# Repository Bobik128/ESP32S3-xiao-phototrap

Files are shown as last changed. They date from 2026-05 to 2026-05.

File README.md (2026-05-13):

# ESP32S3 XIAO Phototrap

ESP32S3 XIAO-based low-power phototrap project.

<p align="center">
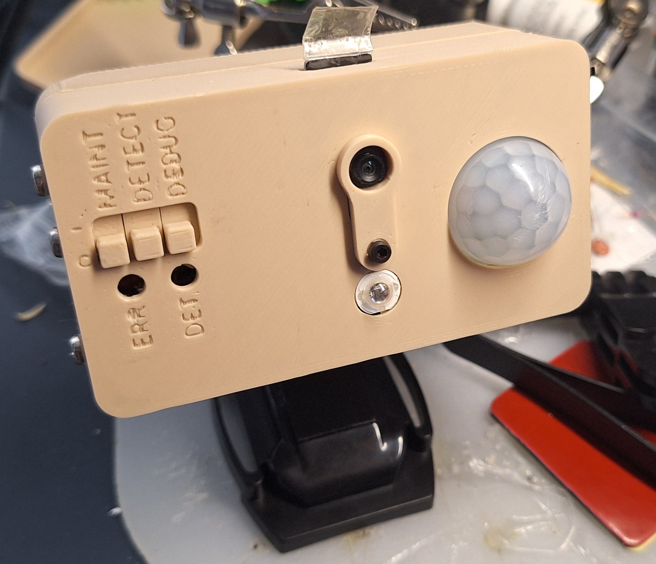
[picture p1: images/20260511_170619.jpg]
  
</p>

This guide shows how to build the phototrap step by step.

First, print all required parts. The files are located in the `cad` directory or on [Onshape](https://cad.onshape.com/documents/ead58119c3828b68d815a62f/w/7087faa25839fe28733057f0/e/a371d4849fa89fe6a0035750).

> https://cad.onshape.com/documents/ead58119c3828b68d815a62f/w/7087faa25839fe28733057f0/e/a371d4849fa89fe6a0035750
> 
> if it doesnt work, just copy the url and put it in browser manually

For printing, I used PLA because it is easy to print with, but for outdoor usage I would recommend ASA.

---

# Features

The phototrap has 3 switches:

- **Maintenance**
- **Detect**
- **Debug**

## Maintenance Mode

The **Maintenance** switch enables maintenance mode.

In this mode, the ESP32 starts a Wi-Fi access point that you can connect to.  
Then open `192.168.4.1` in your browser to access the web interface.

There you can:

- Change SSID and password
- Modify camera settings
- View a live stream
- Turn the IR LED on/off
- Monitor battery level
- View error messages
- And more

The interface supports both:

- Czech
- English

---

## Detect Switch

The **Detect** switch enables automatic recording.

When the PIR sensor detects movement, the ESP32 automatically starts recording video.

---

## Debug Switch

The **Debug** switch enables a small indicator LED below the switch.

The LED lights up whenever movement is detected.

---

## Error LED

The **Error LED** lights up whenever a critical error occurs.

Typical causes:

- Missing SD card
- Broken SD card
- Camera initialization failure

When this happens, the ESP32 also creates a Wi-Fi network and shows the exact error message on the web interface.

---

# Operation

When movement is detected while the **Detect** switch is enabled, recording starts automatically.

Recording continues as long as movement is still being detected.

---

## Power Consumption

When idle, the phototrap consumes approximately **0.3mA**.

With a **10Wh battery**, it can theoretically last for over a year.

The ESP32 wakes up only when:

- Movement is detected
- The maintenance pin is activated

---

## Downloading Videos

Recorded videos can be downloaded:

- Directly from the SD card
- Through the web interface

> **Note:**  
> Videos are encoded in a format that is not natively supported on many mobile phones.  
> Use the VLC player app for playback.

---

## PIR Sensitivity

The PIR sensor has 2 potentiometers accessible from the side of the phototrap:

- **Sensitivity adjustment**
- **Detection hold time**

---

# Miscellaneous

There are 4 possible back cover variants:

- Battery / no battery
- GoPro mount / no GoPro mount

---

# Build Process

# Required Parts

## Screws and Nuts

- 4x M3 × 6mm
- 3x M2 × 4mm
- 2x self-tapping screws, 2mm × 6mm (for mounting the PIR sensor)
- 1x M2 nut

---

## Electronics

- ESP32S3 XIAO Sense with camera expansion board
- OV3660 camera with ~21mm cable
  - OV2640 is not recommended because it cannot reliably enter standby mode and consumes around 20mA instead of ~0.3mA
  - OV5640 has not been tested
- 2.4GHz antenna
- IR LED on a 20mm star cooling pad (850nm recommended)
- Li-Pol battery — specifically `954060 3000mAh 1S / 3.7V`
- Battery connector for the PCB (I used JST-XH 2.54mm)
- 3x DPS switches — `SS12D00G4`
- 3mm red LED
- 3mm blue or green LED
- PIR sensor `HC-SR501`
- NPN transistor (2N2222 recommended)

---

## Resistors

- 2x 330Ω
- 1x 470Ω
- 1x 680Ω
- 2x 1kΩ

For the IR LED, use higher-power resistors (around 1W) and create a resistance between **8Ω and 10Ω**.

Example combination:

- 2.2Ω + 6.8Ω

---

## Additional Materials

- Small prototyping PCB (DPS board)

The exact size does not matter because it must be trimmed to fit.

---

# PIR Sensor Modification

The HC-SR501 normally operates from **4.5–20V**, which is not ideal for this project.

To make it work directly from **3.3V**:

1. Remove the voltage regulator
2. Remove the diode
3. Replace them with solder bridges or short wires

Like this:

<p align="center">
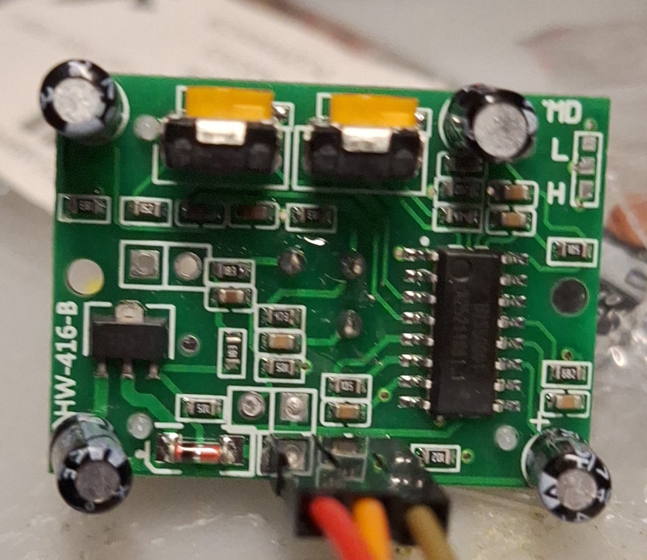
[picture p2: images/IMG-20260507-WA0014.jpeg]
  
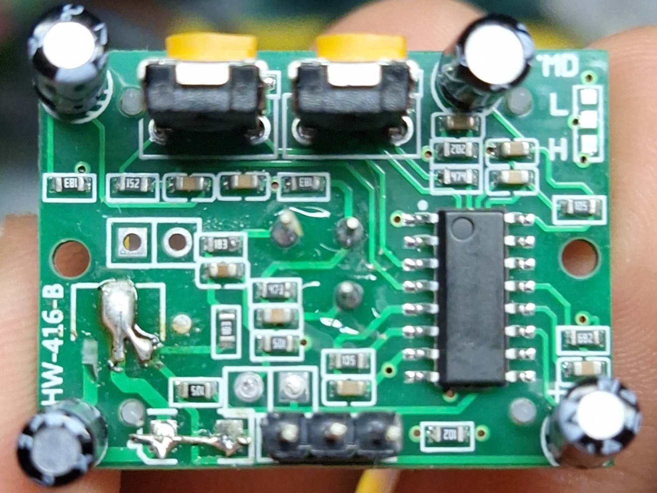
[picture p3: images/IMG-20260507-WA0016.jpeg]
  
</p>

After this modification, the PIR sensor can run directly from 3.3V.

---

# IR LED

<p align="center">
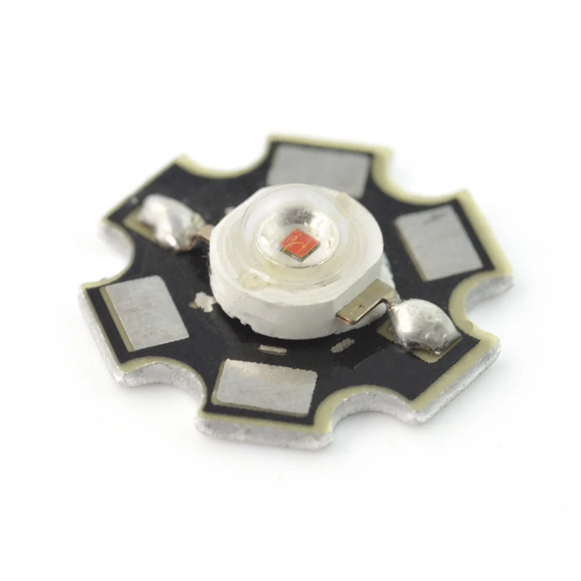
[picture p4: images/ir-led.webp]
  
</p>

Solder wires to the IR LED:

- `+`
- `-`

Before snapping the LED into place, insert the **M2 nut** into its slot.

Then snap the IR LED into position.

---

# ESP32 Assembly

First, separate the ESP32S3 XIAO Sense into its parts:

- Main board
- Expansion board
- Camera
- Antenna

## Assembly Steps

1. Connect the antenna to the main board
2. Slide the camera into its slot
3. Connect the camera to the expansion board
4. Insert the main board into the top slot
5. While inserting it, connect it to the expansion board
6. Route the antenna cable through the cable slot
7. Secure everything using screws or glue

---

# Main PCB

This is the most difficult part because the board must be assembled manually.

The exact component placement is not critical except for:

- Switches
- LEDs
- Battery connector

For placement details, check the Onshape CAD model linked above.

Recommended PCB size:

- Approximately `3.2 × 3.3 cm`

Trim it as necessary.

---

## Circuit Diagram

<a href="images/Phototrap circuit.pdf">
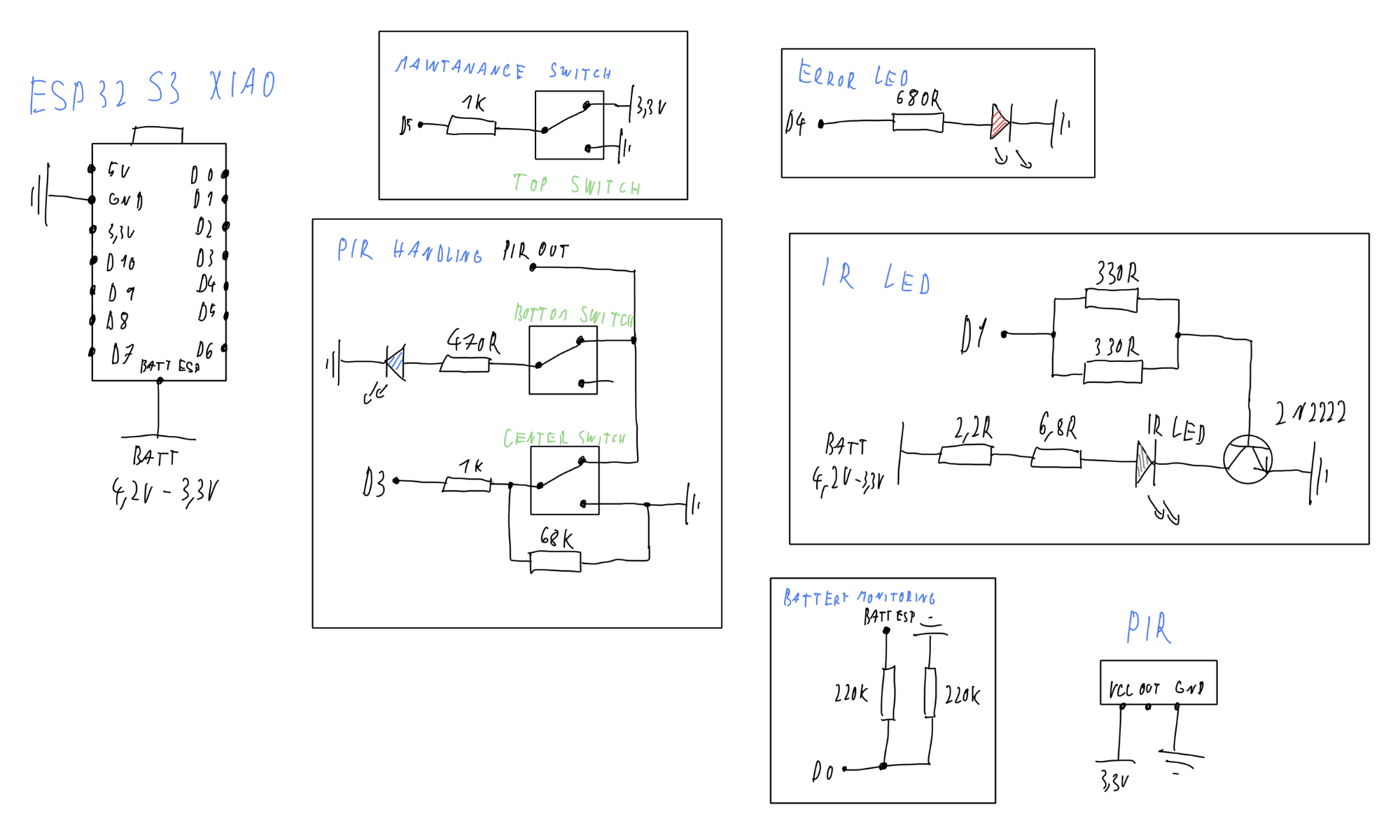
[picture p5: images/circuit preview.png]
  
</a>

---

## PCB Assembly Example

<p align="center">
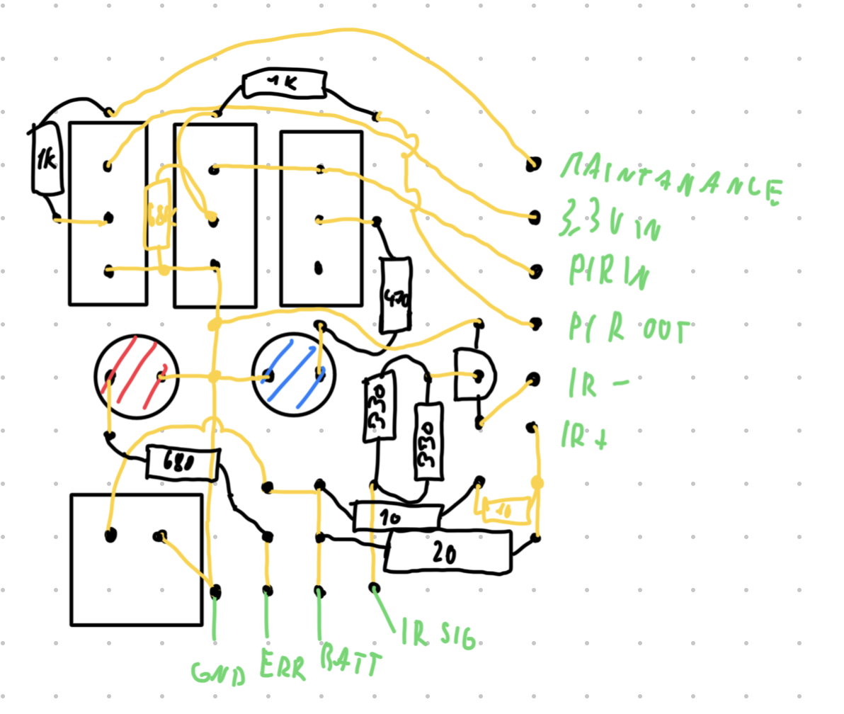
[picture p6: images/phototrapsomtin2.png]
  
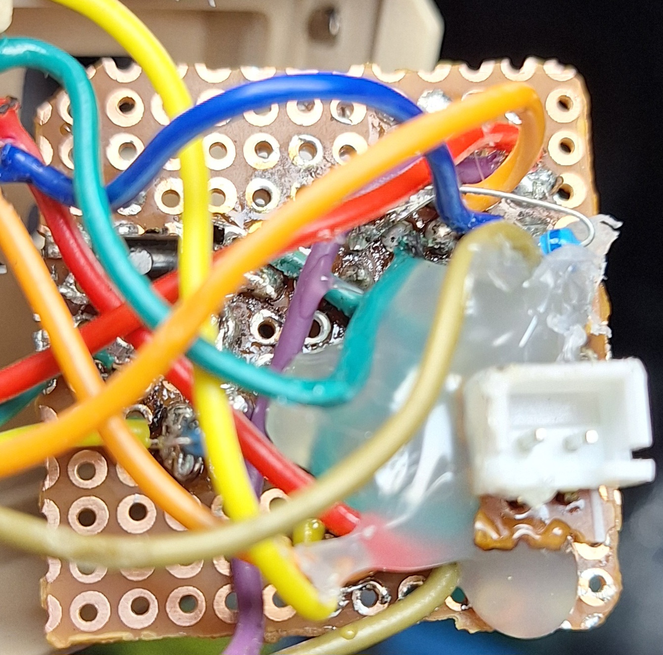
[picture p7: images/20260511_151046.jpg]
  
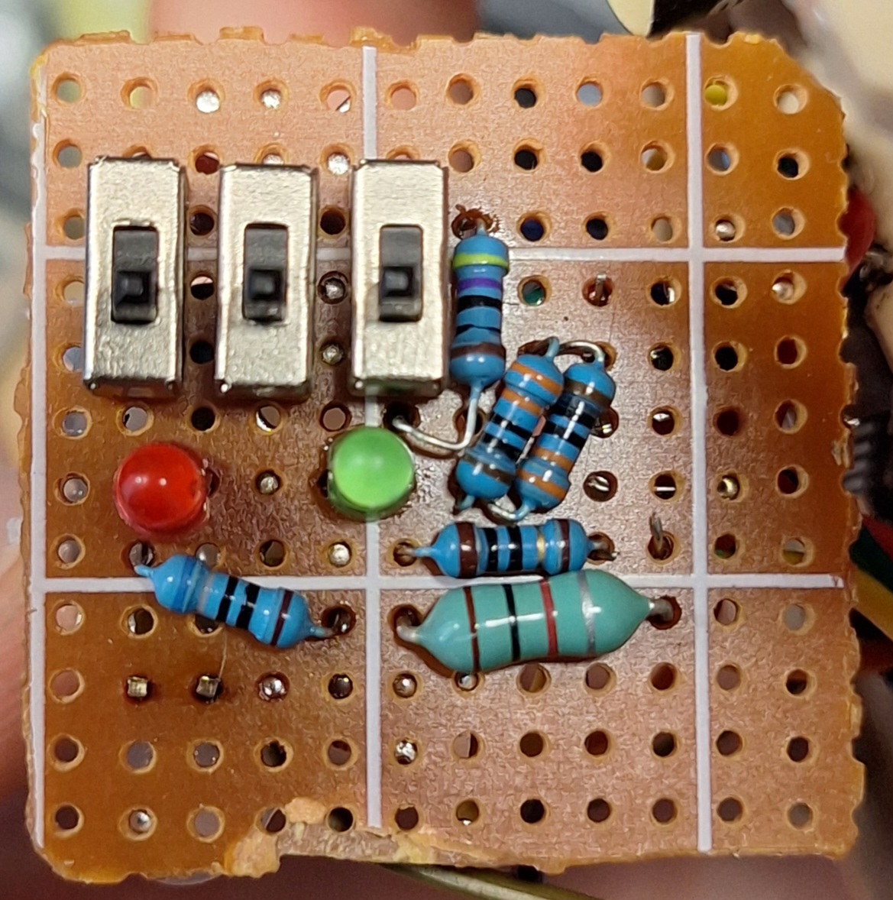
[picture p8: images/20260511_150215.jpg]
  
</p>

---

# Final Assembly

Once everything is assembled:

1. Connect all wires according to the circuit diagram
2. Upload the firmware
3. Test the device

---

# Uploading the Firmware

1. Open the `.ino` file in Arduino IDE
2. Place the `.ino` file into a folder with the same name as the file
3. Install the ESP32 board package
4. Enable **PSRAM**
5. Select the correct board
6. Select the correct flash size (8MB)

---

## Pin Configuration

Check that the GPIO assignments match your hardware.

> These are GPIO numbers, not `D#` labels.

```cpp
static const int PIR_PIN    = 4;
static const int MAINT_PIN  = 3;
static const int IR_LED_PIN = 2;
static const int ERROR_PIN  = 5;

// Battery measurement on GPIO1 through 1/2 voltage divider
static const int BAT_ADC_PIN = 1;
````

```
```

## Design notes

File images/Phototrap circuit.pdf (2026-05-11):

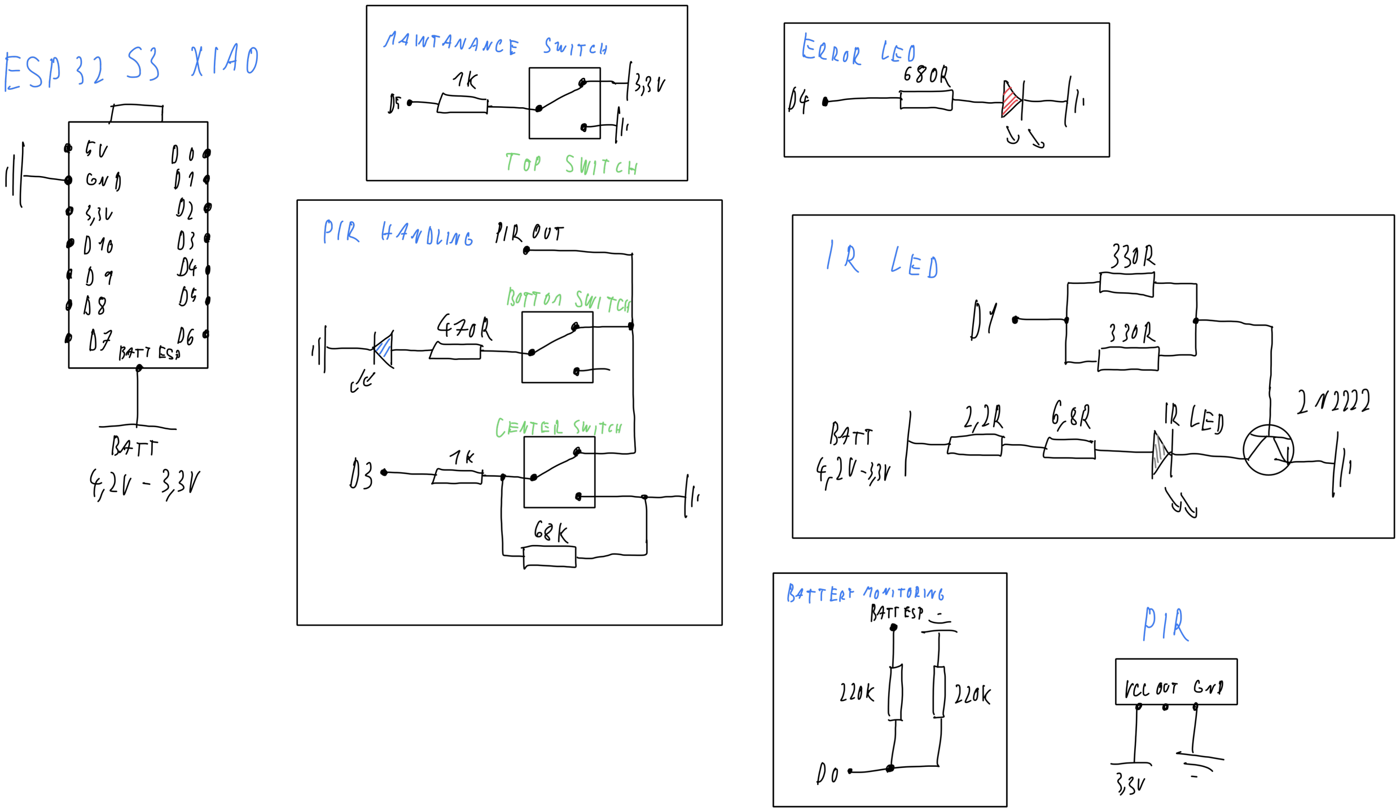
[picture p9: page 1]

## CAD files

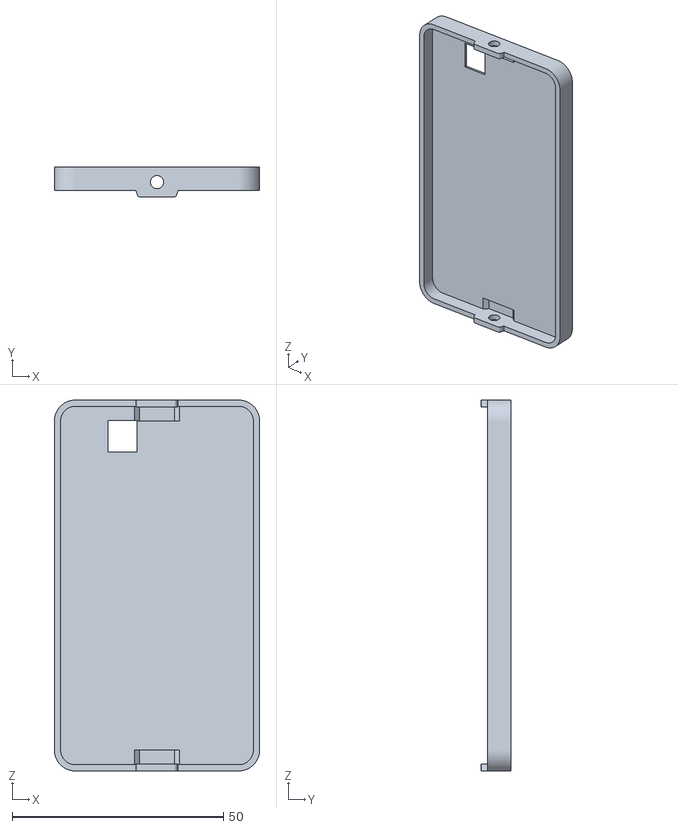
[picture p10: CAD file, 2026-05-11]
cad/stl/main - back-case-no_battery-no_mount.stl
48.6 x 7.03 x 87.8

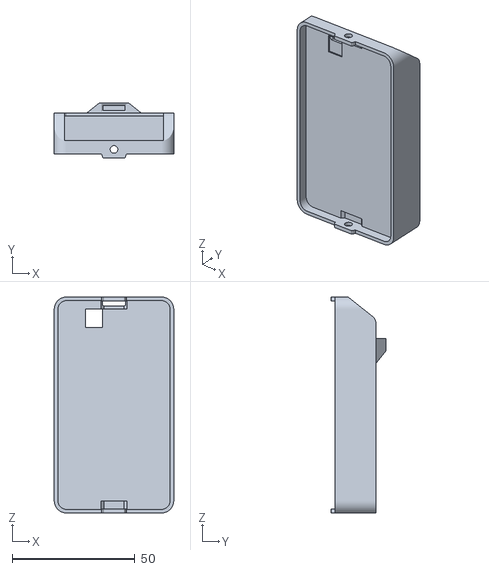
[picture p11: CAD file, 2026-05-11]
cad/stl/main - back-case-no_mount.stl
48.6 x 22.3 x 87.8

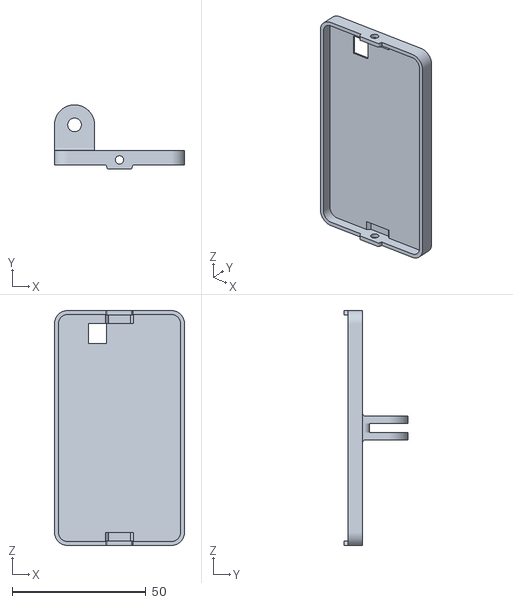
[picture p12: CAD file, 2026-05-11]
cad/stl/main - back-case-no_battery.stl
48.6 x 24.0 x 87.8

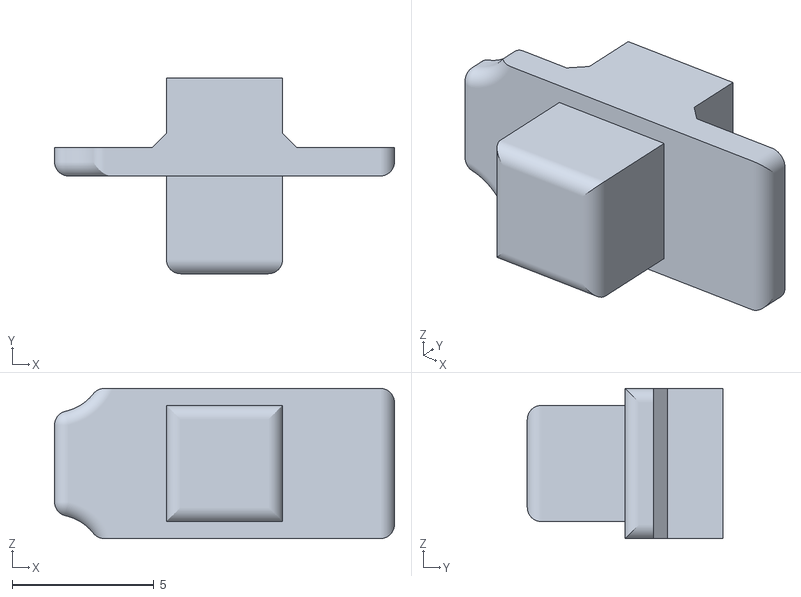
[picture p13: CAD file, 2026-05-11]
cad/stl/Assembly 1 - middle-button.stl
12.0 x 6.90 x 5.30

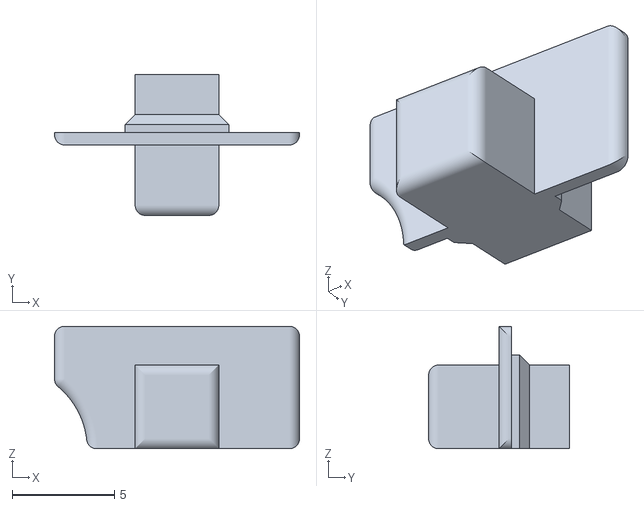
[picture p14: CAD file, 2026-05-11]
cad/stl/Assembly 1 - top-button.stl
12.0 x 6.90 x 6.00

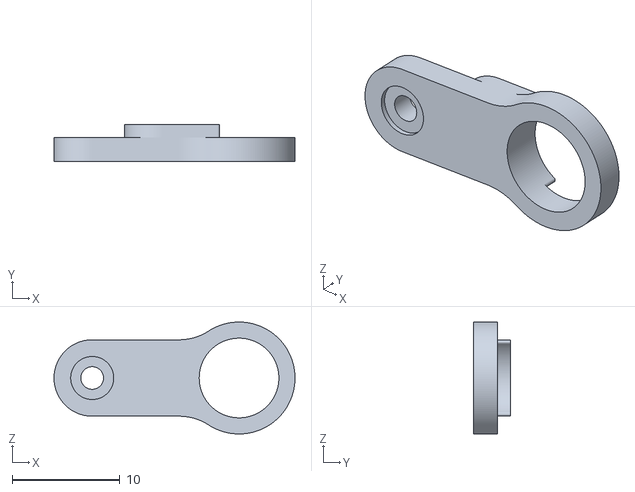
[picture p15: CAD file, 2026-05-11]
cad/stl/Assembly 1 - camera-guard.stl
22.4 x 3.40 x 10.4

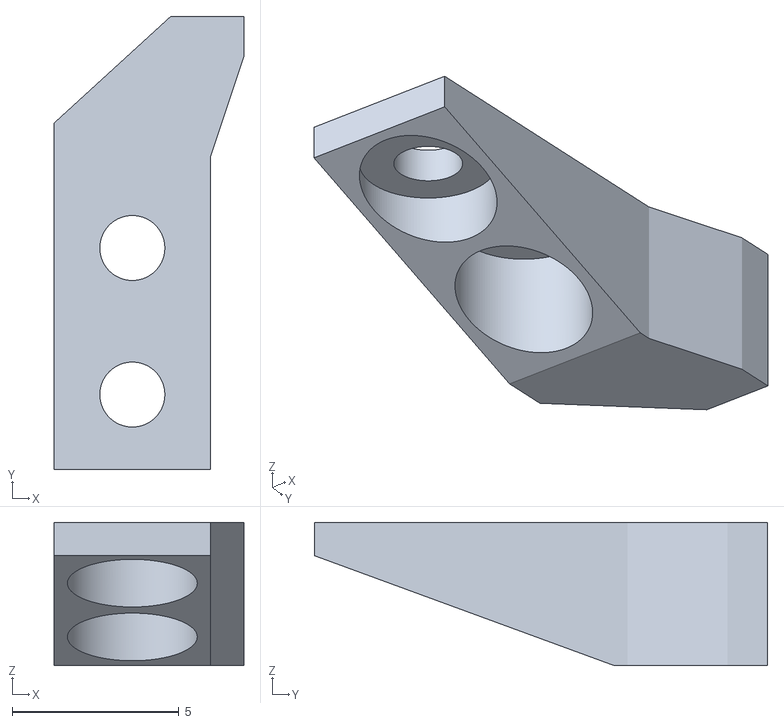
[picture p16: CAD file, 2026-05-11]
cad/stl/Assembly 1 - esp-bracket.stl
5.70 x 13.6 x 4.30

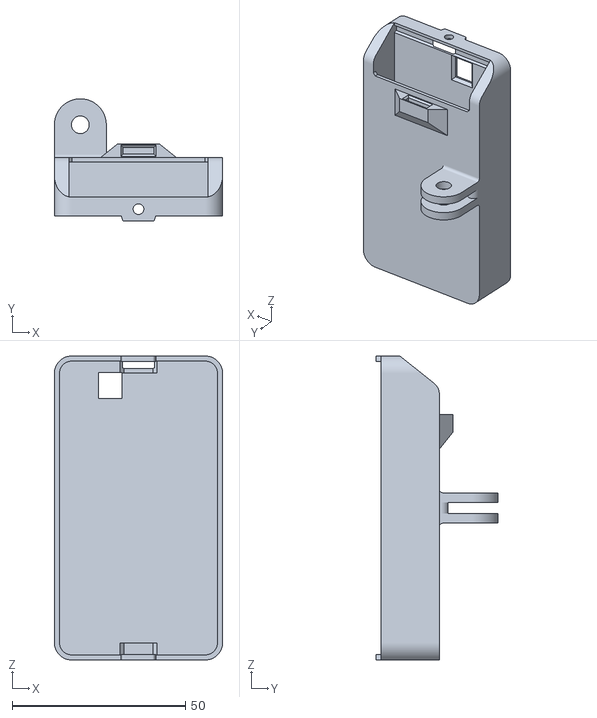
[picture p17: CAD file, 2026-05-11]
cad/stl/Assembly 1 - back-case.stl
48.6 x 35.3 x 87.8

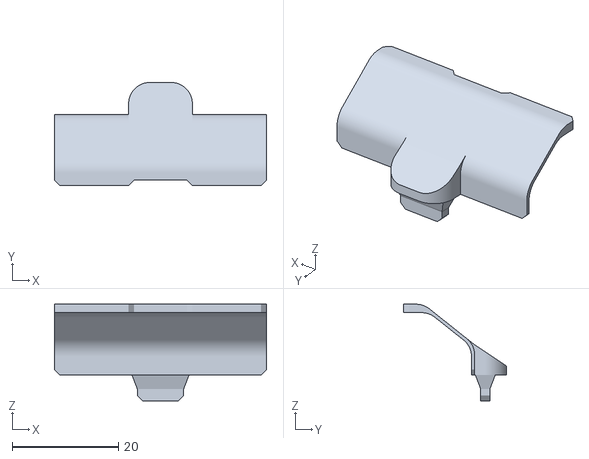
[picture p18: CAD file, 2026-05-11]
cad/stl/Assembly 1 - battery-cover.stl
39.9 x 19.4 x 18.2

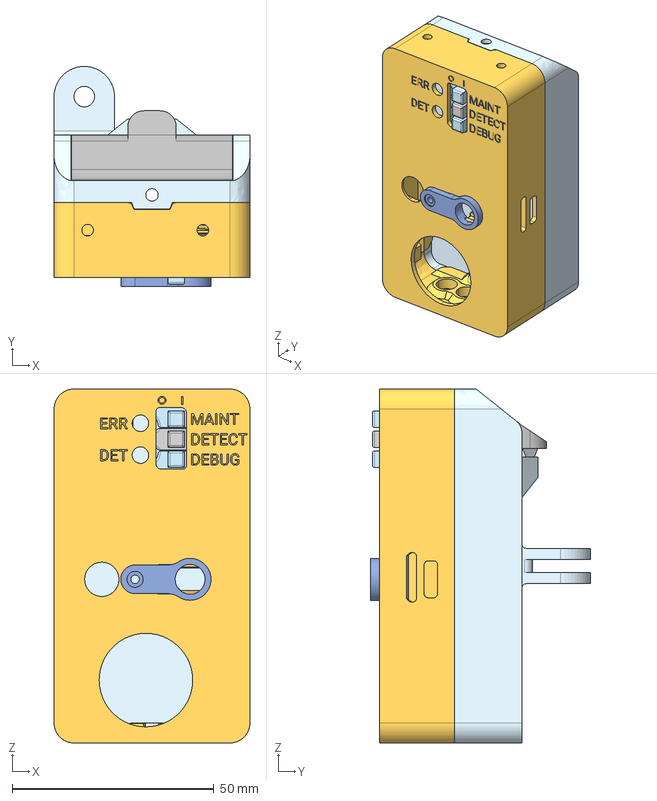
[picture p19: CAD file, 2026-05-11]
cad/phototrap.step
48.6 x 54.6 x 87.8 mm
middle-button
battery-cover
camera-guard
low-button
back-case
top-button
esp-bracket

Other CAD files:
cad/stl/Assembly 1 - low-button.stl

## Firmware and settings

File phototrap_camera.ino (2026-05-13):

#include <Arduino.h>
#include <esp_camera.h>
#include <driver/rtc_io.h>
#include <FS.h>
#include <SD.h>
#include <SPI.h>
#include <WiFi.h>
#include <WebServer.h>
#include <Preferences.h>

// ======================================================================
// Camera pins: XIAO ESP32S3 Sense
// ======================================================================

static const int XCLK_PIN  = 10;
static const int PCLK_PIN  = 13;
static const int VSYNC_PIN = 38;
static const int HREF_PIN  = 47;

static const int D0_PIN = 15;
static const int D1_PIN = 17;
static const int D2_PIN = 18;
static const int D3_PIN = 16;
static const int D4_PIN = 14;
static const int D5_PIN = 12;
static const int D6_PIN = 11;
static const int D7_PIN = 48;

static const int SDA_PIN   = 40;
static const int SCL_PIN   = 39;
static const int PWDN_PIN  = -1;
static const int RESET_PIN = -1;

// ======================================================================
// SD card pins: XIAO ESP32S3 Sense
// NOTE: SD_CS = GPIO21. On the XIAO ESP32S3 Sense, GPIO21 is also tied
// to the onboard user LED, so SD writes visibly flash the onboard LED.
// This is a board-level hardware conflict, not controllable in firmware.
// ======================================================================

static const int SD_CS   = 21;
static const int SD_SCK  = 7;
static const int SD_MISO = 8;
static const int SD_MOSI = 9;

// ======================================================================
// User pins
// ======================================================================

static const int PIR_PIN    = 4;
static const int MAINT_PIN  = 3;
static const int IR_LED_PIN = 2;
static const int ERROR_PIN  = 5;  // HIGH = fatal error / error AP active

// Battery measurement on GPIO1 through 1/2 voltage divider
static const int BAT_ADC_PIN = 1;
static const float BAT_DIVIDER_RATIO = 2.0;

// ======================================================================
// Config files / defaults
// ======================================================================

static const char *DEFAULT_AP_SSID = "Phototrap-AP";
static const char *DEFAULT_AP_PASS = "12345678";
static const char *AP_CONFIG_FILE = "/ap_config.txt";
static const char *CAMERA_CONFIG_FILE = "/camera_config.txt";

String apSsid = DEFAULT_AP_SSID;
String apPass = DEFAULT_AP_PASS;
String uiLang = "en";

Preferences prefs;

// ======================================================================
// Runtime camera settings, loaded from /camera_config.txt
// ======================================================================

static framesize_t cameraFrameSize = FRAMESIZE_FHD;
static String cameraFrameSizeId = "FHD";

static int jpegQuality = 4;     // 4 = best/largest, 63 = worst/smallest
static uint16_t aviFps = 5;
static int xclkHz = 16000000;

static bool cameraVFlip = true;
static bool cameraHMirror = false;
static bool recordingIrLedEnabled = true;

static const uint32_t RECORD_BLOCK_MS = 5000;
static const uint16_t MAX_FRAMES = 2000;

struct CameraResolutionOption {
  const char *id;
  const char *label;
  framesize_t frameSize;
  uint16_t width;
  uint16_t height;
  uint16_t maxFps;
};

static const CameraResolutionOption CAMERA_RES_OPTIONS[] = {
  {"96X96",   "96 x 96",      FRAMESIZE_96X96,   96,   96,   30},
  {"QQVGA",   "160 x 120",    FRAMESIZE_QQVGA,   160,  120,  30},
  {"QCIF",    "176 x 144",    FRAMESIZE_QCIF,    176,  144,  30},
  {"HQVGA",   "240 x 176",    FRAMESIZE_HQVGA,   240,  176,  30},
  {"240X240", "240 x 240",    FRAMESIZE_240X240, 240,  240,  25},
  {"QVGA",    "320 x 240",    FRAMESIZE_QVGA,    320,  240,  25},
  {"CIF",     "400 x 296",    FRAMESIZE_CIF,     400,  296,  20},
  {"HVGA",    "480 x 320",    FRAMESIZE_HVGA,    480,  320,  20},
  {"VGA",     "640 x 480",    FRAMESIZE_VGA,     640,  480,  15},
  {"SVGA",    "800 x 600",    FRAMESIZE_SVGA,    800,  600,  10},
  {"XGA",     "1024 x 768",   FRAMESIZE_XGA,     1024, 768,  8},
  {"HD",      "1280 x 720",   FRAMESIZE_HD,      1280, 720,  6},
  {"SXGA",    "1280 x 1024",  FRAMESIZE_SXGA,    1280, 1024, 5},
  {"UXGA",    "1600 x 1200",  FRAMESIZE_UXGA,    1600, 1200, 5},
  {"FHD",     "1920 x 1080",  FRAMESIZE_FHD,     1920, 1080, 5},
  {"P_HD",    "720 x 1280",   FRAMESIZE_P_HD,    720,  1280, 4},
  {"P_3MP",   "864 x 1536",   FRAMESIZE_P_3MP,   864,  1536, 3},
  {"QXGA",    "2048 x 1536",  FRAMESIZE_QXGA,    2048, 1536, 3}
};

static const size_t CAMERA_RES_OPTION_COUNT =
  sizeof(CAMERA_RES_OPTIONS) / sizeof(CAMERA_RES_OPTIONS[0]);

// ======================================================================
// Globals
// ======================================================================

WebServer server(80);

bool maintenanceActive = false;
bool sdAvailable = false;
bool cameraAvailable = false;

bool recordingActive = false;
bool irLedOverrideActive = false;
bool irLedOutputActive = false;

// Blocking stream/download handlers set this flag if MAINT goes LOW.
// The main loop performs the actual AP shutdown once the handler exits.
bool maintenanceShutdownRequested = false;

String criticalError = "";

uint32_t nextVideoId = 1;

// ======================================================================
// Language helpers
// ======================================================================

bool isCzech() {
  return uiLang == "cs";
}

String tr(const String &en, const String &cs) {
  return isCzech() ? cs : en;
}

String activeLangClass(const String &lang) {
  return uiLang == lang ? " activeLang" : "";
}

void saveUiLanguage(const String &lang) {
  if (lang != "en" && lang != "cs") return;

  uiLang = lang;

  prefs.begin("phototrap", false);
  prefs.putString("ui_lang", uiLang);
  prefs.end();
}

void handleSetLanguage() {
  String lang = server.arg("lang");

  if (lang == "cs" || lang == "en") {
    saveUiLanguage(lang);
  }

  server.sendHeader("Location", "/");
  server.send(303);
}

// ======================================================================
// Formatting / log helpers
// ======================================================================

String formatFileSize(uint64_t bytes) {
  if (bytes >= 1024ULL * 1024ULL) {
    return String((float)bytes / (1024.0f * 1024.0f), 2) + " MB";
  }

  if (bytes >= 1024ULL) {
    return String((float)bytes / 1024.0f, 1) + " KB";
  }

  return String((uint32_t)bytes) + " B";
}

static const size_t LOG_LINES = 120;
String logBuffer[LOG_LINES];
size_t logIndex = 0;

void logLine(const String &msg) {
  String line = "[" + String(millis()) + "] " + msg;

  Serial.println(line);

  logBuffer[logIndex % LOG_LINES] = line;
  logIndex++;

  if (sdAvailable) {
    File f = SD.open("/phototrap.log", FILE_APPEND);
    if (f) {
      f.println(line);
      f.close();
    }
  }
}

String logText() {
  String text;

  size_t count = min((size_t)LOG_LINES, logIndex);
  size_t start = (logIndex > LOG_LINES) ? (logIndex - LOG_LINES) : 0;

  for (size_t i = start; i < start + count; i++) {
    text += logBuffer[i % LOG_LINES];
    text += "\n";
  }

  return text;
}

void handleLog() {
  String html;

  html += "<html><head><meta charset='UTF-8'><title>Phototrap Log</title>";
  html += "<meta http-equiv='refresh' content='3'>";
  html += "</head><body>";
  html += "<h1>Phototrap Log</h1>";
  html += "<p><a href='/'>";
  html += tr("Back", "Zpět");
  html += "</a></p>";
  html += "<pre>";
  html += logText();
  html += "</pre>";
  html += "</body></html>";

  server.send(200, "text/html; charset=utf-8", html);
}

void handleLogData() {
  server.send(200, "text/plain; charset=utf-8", logText());
}

// ======================================================================
// IR LED control
// ======================================================================

void updateIrLedOutput() {
  bool shouldBeOn =
    (recordingActive && recordingIrLedEnabled) ||
    irLedOverrideActive;

  digitalWrite(IR_LED_PIN, shouldBeOn ? HIGH : LOW);
  irLedOutputActive = shouldBeOn;
}

void setRecordingLedState(bool active) {
  recordingActive = active;
  updateIrLedOutput();
}

void setIrLedOverride(bool active) {
  if (irLedOverrideActive == active) {
    updateIrLedOutput();
    return;
  }

  irLedOverrideActive = active;
  updateIrLedOutput();

  logLine(active ? "IR LED override enabled" : "IR LED override disabled");
}

void handleLedOverride() {
  String state = server.arg("state");

  if (state == "1" || state == "on" || state == "true") {
    setIrLedOverride(true);
    server.send(200, "text/plain; charset=utf-8", tr("IR LED override ON", "Vynucené zapnutí IR LED zapnuto"));
    return;
  }

  setIrLedOverride(false);
  server.send(200, "text/plain; charset=utf-8", tr("IR LED override OFF", "Vynucené zapnutí IR LED vypnuto"));
}

// ======================================================================
// Pin / battery helpers
// ======================================================================

bool pirActive() {
  return digitalRead(PIR_PIN) == HIGH;
}

bool maintenancePinActive() {
  return digitalRead(MAINT_PIN) == HIGH;
}

uint32_t readBatteryMilliVolts() {
  const int samples = 16;
  uint32_t sum = 0;

  for (int i = 0; i < samples; i++) {
    sum += analogReadMilliVolts(BAT_ADC_PIN);
    delay(2);
  }

  uint32_t adcMv = sum / samples;
  return (uint32_t)(adcMv * BAT_DIVIDER_RATIO);
}

int batteryPercentFromMilliVolts(uint32_t mv) {
  struct Point {
    uint16_t mv;
    uint8_t pct;
  };

  static const Point table[] = {
    {4060, 100},
    {4020, 95},
    {3980, 90},
    {3940, 85},
    {3900, 80},
    {3860, 75},
    {3820, 70},
    {3780, 65},
    {3740, 60},
    {3700, 55},
    {3660, 50},
    {3620, 40},
    {3580, 30},
    {3540, 20},
    {3500, 15},
    {3450, 10},
    {3400, 5},
    {3300, 0}
  };

  static const size_t count = sizeof(table) / sizeof(table[0]);

  if (mv >= table[0].mv) return table[0].pct;
  if (mv <= table[count - 1].mv) return table[count - 1].pct;

  for (size_t i = 0; i < count - 1; i++) {
    if (mv <= table[i].mv && mv >= table[i + 1].mv) {
      uint16_t mvHigh = table[i].mv;
      uint16_t mvLow  = table[i + 1].mv;
      uint8_t pctHigh = table[i].pct;
      uint8_t pctLow  = table[i + 1].pct;

      float t = (float)(mv - mvLow) / (float)(mvHigh - mvLow);
      return pctLow + (int)((pctHigh - pctLow) * t);
    }
  }

  return 0;
}

void handleBatteryData() {
  uint32_t batMv = readBatteryMilliVolts();
  int batPct = batteryPercentFromMilliVolts(batMv);

  String json = "{";
  json += "\"mv\":" + String(batMv) + ",";
  json += "\"pct\":" + String(batPct);
  json += "}";

  server.send(200, "application/json; charset=utf-8", json);
}

// ======================================================================
// Camera settings helpers
// ======================================================================

const CameraResolutionOption *findCameraResolutionOption(const String &id) {
  for (size_t i = 0; i < CAMERA_RES_OPTION_COUNT; i++) {
    if (id == CAMERA_RES_OPTIONS[i].id) {
      return &CAMERA_RES_OPTIONS[i];
    }
  }

  return nullptr;
}

const CameraResolutionOption *currentCameraResolutionOption() {
  const CameraResolutionOption *opt = findCameraResolutionOption(cameraFrameSizeId);
  if (opt) return opt;

  return findCameraResolutionOption("FHD");
}

void applyCameraResolutionOption(const CameraResolutionOption *opt) {
  if (!opt) {
    opt = findCameraResolutionOption("FHD");
  }

  cameraFrameSizeId = opt->id;
  cameraFrameSize = opt->frameSize;

  if (aviFps < 1) {
    aviFps = 1;
  }

  if (aviFps > opt->maxFps) {
    aviFps = opt->maxFps;
  }
}

void clampCameraSettings() {
  const CameraResolutionOption *opt = currentCameraResolutionOption();
  applyCameraResolutionOption(opt);

  if (jpegQuality < 4) jpegQuality = 4;
  if (jpegQuality > 63) jpegQuality = 63;

  if (xclkHz != 10000000 && xclkHz != 12000000 &&
      xclkHz != 16000000 && xclkHz != 20000000) {
    xclkHz = 16000000;
  }
}

bool writeCameraSettingsToSD() {
  if (!sdAvailable) {
    logLine("WARNING: Cannot write camera config, SD unavailable");
    return false;
  }

  if (SD.exists(CAMERA_CONFIG_FILE)) {
    SD.remove(CAMERA_CONFIG_FILE);
  }

  File f = SD.open(CAMERA_CONFIG_FILE, FILE_WRITE);

  if (!f) {
    logLine("ERROR: Failed to write /camera_config.txt");
    return false;
  }

  clampCameraSettings();

  f.println("# Phototrap camera settings");
  f.println("# resolution: 96X96, QQVGA, QCIF, HQVGA, 240X240, QVGA, CIF, HVGA, VGA, SVGA, XGA, HD, SXGA, UXGA, FHD, P_HD, P_3MP, QXGA");
  f.println("# jpeg_quality: 4 = best/largest, 63 = worst/smallest");
  f.println("# fps is clamped based on resolution");
  f.println("# xclk_hz: 10000000, 12000000, 16000000, 20000000");
  f.println("# recording_ir_led: 1 = IR LED turns on while recording, 0 = recording does not use IR LED");

  f.print("resolution=");
  f.println(cameraFrameSizeId);

  f.print("fps=");
  f.println(aviFps);

  f.print("jpeg_quality=");
  f.println(jpegQuality);

  f.print("xclk_hz=");
  f.println(xclkHz);

  f.print("vflip=");
  f.println(cameraVFlip ? 1 : 0);

  f.print("hmirror=");
  f.println(cameraHMirror ? 1 : 0);

  f.print("recording_ir_led=");
  f.println(recordingIrLedEnabled ? 1 : 0);

  f.close();

  logLine("Camera settings written to SD: /camera_config.txt");
  return true;
}

bool loadCameraSettingsFromSD() {
  if (!sdAvailable) {
    return false;
  }

  if (!SD.exists(CAMERA_CONFIG_FILE)) {
    logLine("Camera config not found, writing defaults");
    writeCameraSettingsToSD();
    return false;
  }

  File f = SD.open(CAMERA_CONFIG_FILE, FILE_READ);

  if (!f) {
    logLine("WARNING: Failed to read /camera_config.txt");
    return false;
  }

  while (f.available()) {
    String line = f.readStringUntil('\n');
    line.trim();

    if (line.length() == 0) continue;
    if (line.startsWith("#")) continue;

    int eq = line.indexOf('=');
    if (eq <= 0) continue;

    String key = line.substring(0, eq);
    String val = line.substring(eq + 1);

    key.trim();
    val.trim();

    if (key == "resolution") {
      const CameraResolutionOption *opt = findCameraResolutionOption(val);
      if (opt) {
        cameraFrameSizeId = val;
        cameraFrameSize = opt->frameSize;
      } else {
        logLine("WARNING: Invalid camera resolution in config: " + val);
      }
    } else if (key == "fps") {
      aviFps = (uint16_t)val.toInt();
    } else if (key == "jpeg_quality") {
      jpegQuality = val.toInt();
    } else if (key == "xclk_hz") {
      xclkHz = val.toInt();
    } else if (key == "vflip") {
      cameraVFlip = (val.toInt() != 0);
    } else if (key == "hmirror") {
      cameraHMirror = (val.toInt() != 0);
    } else if (key == "recording_ir_led") {
      recordingIrLedEnabled = (val.toInt() != 0);
    }
  }

  f.close();

  clampCameraSettings();

  logLine("Camera settings loaded from SD");
  logLine("Resolution: " + cameraFrameSizeId);
  logLine("FPS: " + String(aviFps));
  logLine("JPEG quality: " + String(jpegQuality));
  logLine("XCLK Hz: " + String(xclkHz));
  logLine("VFlip: " + String(cameraVFlip));
  logLine("HMirror: " + String(cameraHMirror));
  logLine("Recording IR LED: " + String(recordingIrLedEnabled));

  return true;
}

// ======================================================================
// AP settings: NVS + SD backup
// ======================================================================

bool apSettingsAreValid(const String &ssid, const String &pass, String &error) {
  if (ssid.length() == 0) {
    error = "SSID cannot be empty";
    return false;
  }

  if (ssid.length() > 31) {
    error = "SSID must be 31 characters or less";
    return false;
  }

  if (pass.length() < 8) {
    error = "Password must be at least 8 characters";
    return false;
  }

  if (pass.length() > 63) {
    error = "Password must be 63 characters or less";
    return false;
  }

  return true;
}

void saveApSettingsToNVSOnly(const String &ssid, const String &pass) {
  prefs.begin("phototrap", false);
  prefs.putString("ap_ssid", ssid);
  prefs.putString("ap_pass", pass);
  prefs.end();
}

bool writeApSettingsToSD() {
  if (!sdAvailable) {
    return false;
  }

  if (SD.exists(AP_CONFIG_FILE)) {
    SD.remove(AP_CONFIG_FILE);
  }

  File f = SD.open(AP_CONFIG_FILE, FILE_WRITE);

  if (!f) {
    logLine("WARNING: Failed to write /ap_config.txt");
    return false;
  }

  f.println("# Phototrap AP settings");
  f.println("# Edit this file on the SD card to recover/change AP access.");
  f.println("# Password must be at least 8 characters.");
  f.print("ssid=");
  f.println(apSsid);
  f.print("pass=");
  f.println(apPass);
  f.close();

  logLine("AP settings written to SD: /ap_config.txt");
  return true;
}

bool loadApSettingsFromSD() {
  if (!sdAvailable) return false;
  if (!SD.exists(AP_CONFIG_FILE)) return false;

  File f = SD.open(AP_CONFIG_FILE, FILE_READ);

  if (!f) {
    logLine("WARNING: Failed to read /ap_config.txt");
    return false;
  }

  String ssid = "";
  String pass = "";

  while (f.available()) {
    String line = f.readStringUntil('\n');
    line.trim();

    if (line.length() == 0) continue;
    if (line.startsWith("#")) continue;

    int eq = line.indexOf('=');
    if (eq <= 0) continue;

    String key = line.substring(0, eq);
    String val = line.substring(eq + 1);

    key.trim();
    val.trim();

    if (key == "ssid") ssid = val;
    else if (key == "pass") pass = val;
  }

  f.close();

  String error;
  if (!apSettingsAreValid(ssid, pass, error)) {
    logLine("WARNING: Ignoring invalid /ap_config.txt: " + error);
    return false;
  }

  apSsid = ssid;
  apPass = pass;

  saveApSettingsToNVSOnly(apSsid, apPass);

  logLine("AP settings loaded from SD and synced to NVS");
  logLine("AP SSID from SD: " + apSsid);

  return true;
}

void loadApSettingsFromNVS() {
  prefs.begin("phototrap", true);

  apSsid = prefs.getString("ap_ssid", DEFAULT_AP_SSID);
  apPass = prefs.getString("ap_pass", DEFAULT_AP_PASS);
  uiLang = prefs.getString("ui_lang", "en");

  prefs.end();

  String error;
  if (!apSettingsAreValid(apSsid, apPass, error)) {
    apSsid = DEFAULT_AP_SSID;
    apPass = DEFAULT_AP_PASS;
  }

  if (uiLang != "en" && uiLang != "cs") {
    uiLang = "en";
  }

  logLine("AP settings loaded from NVS");
  logLine("AP SSID: " + apSsid);
  logLine("UI language: " + uiLang);
}

void syncApSettingsWithSD() {
  if (!sdAvailable) return;

  if (loadApSettingsFromSD()) return;

  writeApSettingsToSD();
}

bool saveApSettings(const String &ssid, const String &pass, String &error) {
  String cleanSsid = ssid;
  String cleanPass = pass;

  cleanSsid.trim();
  cleanPass.trim();

  if (!apSettingsAreValid(cleanSsid, cleanPass, error)) {
    return false;
  }

  apSsid = cleanSsid;
  apPass = cleanPass;

  saveApSettingsToNVSOnly(apSsid, apPass);
  writeApSettingsToSD();

  logLine("AP settings saved");
  logLine("New AP SSID: " + apSsid);

  return true;
}

// ======================================================================
// ID / filename helpers
// ======================================================================

uint32_t parseVideoId(String name) {
  if (name.startsWith("/")) {
    name.remove(0, 1);
  }

  if (!name.startsWith("video_") || !name.endsWith(".avi")) {
    return 0;
  }

  int underscore = name.indexOf('_');
  int dot = name.lastIndexOf('.');

  if (underscore < 0 || dot <= underscore) {
    return 0;
  }

  return (uint32_t)name.substring(underscore + 1, dot).toInt();
}

uint32_t scanHighestExistingVideoId() {
  uint32_t maxIdx = 0;

  File root = SD.open("/");

  if (!root) {
    return 0;
  }

  while (true) {
    File file = root.openNextFile();
    if (!file) break;

    if (!file.isDirectory()) {
      uint32_t id = parseVideoId(file.name());
      if (id > maxIdx) {
        maxIdx = id;
      }
    }

    file.close();
  }

  root.close();

  return maxIdx;
}

uint32_t readLastUsedIdFile() {
  if (!SD.exists("/last_id.txt")) {
    return 0;
  }

  File f = SD.open("/last_id.txt", FILE_READ);
  if (!f) {
    return 0;
  }

  String s = f.readStringUntil('\n');
  f.close();
  s.trim();

  return (uint32_t)s.toInt();
}

bool writeLastUsedIdFile(uint32_t id) {
  if (SD.exists("/last_id.txt")) {
    SD.remove("/last_id.txt");
  }

  File f = SD.open("/last_id.txt", FILE_WRITE);
  if (!f) {
    logLine("WARNING: Failed to write /last_id.txt");
    return false;
  }

  f.println(String(id));
  f.close();

  return true;
}

void initVideoIdCounter() {
  if (!sdAvailable) {
    nextVideoId = 1;
    return;
  }

  uint32_t highestExisting = scanHighestExistingVideoId();
  uint32_t lastUsed = readLastUsedIdFile();

  uint32_t effectiveLast = max(highestExisting, lastUsed);

  nextVideoId = effectiveLast + 1;

  writeLastUsedIdFile(effectiveLast);

  logLine("Highest existing video ID: " + String(highestExisting));
  logLine("Last used video ID: " + String(lastUsed));
  logLine("Next video ID: " + String(nextVideoId));
}

String makeFilename() {
  if (!sdAvailable) {
    return "/video_error.avi";
  }

  for (uint32_t attempt = 0; attempt < 1000; attempt++) {
    uint32_t id = nextVideoId++;

    writeLastUsedIdFile(id);

    char buf[32];
    snprintf(buf, sizeof(buf), "/video_%05lu.avi", (unsigned long)id);

    if (!SD.exists(buf)) {
      logLine("Allocated filename: " + String(buf));
      return String(buf);
    }

    logLine("WARNING: Allocated filename already exists, skipping: " + String(buf));
  }

  return "/video_overflow.avi";
}
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
void loop() {
}

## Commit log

2026-05-11 Update README with build process details
    Added detailed instructions for modifying PIR sensor and assembling IR LED and ESP components.
2026-05-11 Update README with assembly instructions and finalization
    Added assembly instructions and finalization steps for the circuit.
2026-05-11 Revise README for ESP32S3 XIAO Phototrap
    Updated README with improved clarity and formatting.
2026-05-13 Rename Phototrap circuit.png to phototrapsomtin.png
2026-05-13 Fix image filename case in README.md
2026-05-13 Fix image formatting in PCB Assembly Example section
2026-05-13 Update PCB Assembly image in README.md
